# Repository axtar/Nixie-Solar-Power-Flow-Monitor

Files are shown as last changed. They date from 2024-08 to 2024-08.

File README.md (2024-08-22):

# Nixie Solar Power Flow Monitor
## This repository contains some information and ideas for building a nixie solar power flow monitor.


## WARNING: nixies need high voltage to light up. If you choose to build or use the device, you are doing so at your own risk. 

**Notes:**
- **The firmware is designed to work with a specific Fronius hybrid inverter using the Solar API V1. Firmware changes are needed for other inverters and configurations.**
- **This repository does not contain a complete project design. The design of the high voltage power supply (170V / ≥75mA) is not provided. I recommend using a professionally designed and extensively tested HV PSU.** 
- **Be aware that I'm just an electronics hobbyist and nixie enthusiast. However, this repository is only intended for suitable qualified electronics engineers who are familiar with nixie tubes.**
- **Please read all documents in [Docs](Docs) before deciding whether to build the device.**
- **I'm not affiliated with any of the service providers mentioned in this project.**
  
**Status:** 
- Software: ready to be reviewed (beta)
- Hardware: ready to be reviewed (beta)

**Displayed Values:**

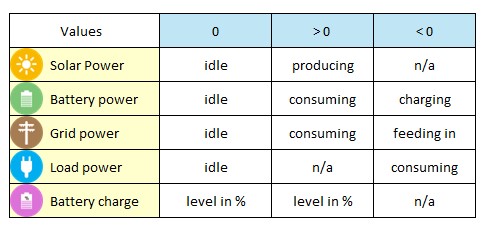
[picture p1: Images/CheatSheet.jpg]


**Nixie tubes used in this project:**
- 15 x IN-12A or IN-12B
- 10 x IN-15A
- 4 x IN-15B

**Additional Features:**

- LED backlight
- Ethernet connection

**Nixie Solar Power Flow Monitor**

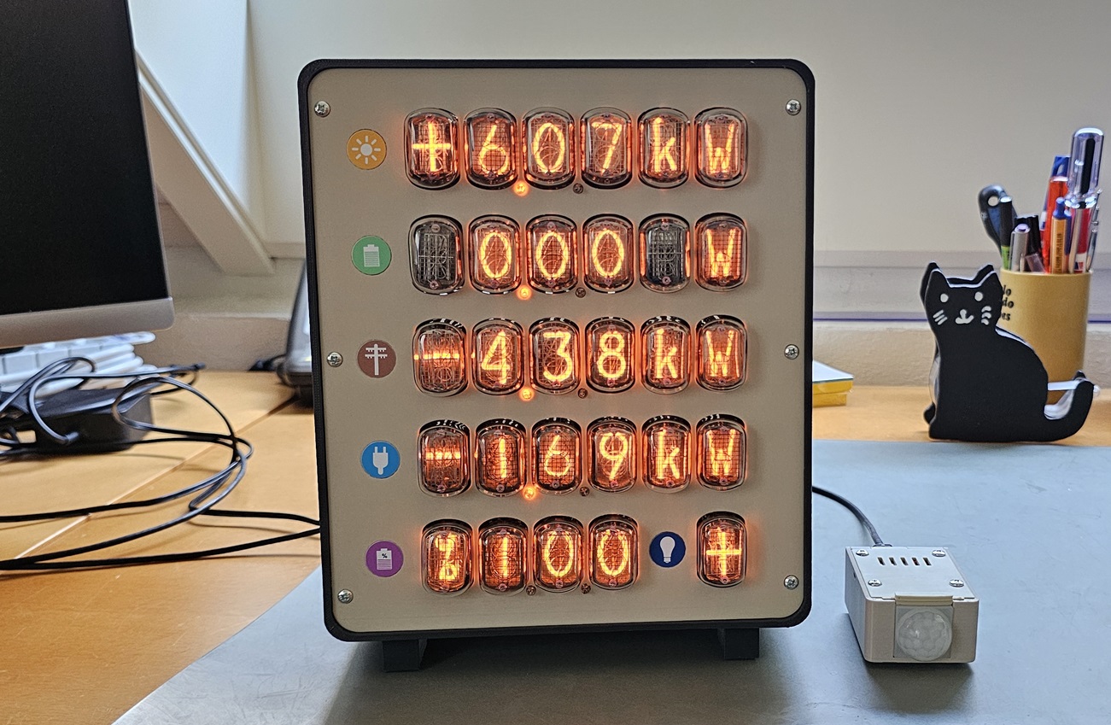
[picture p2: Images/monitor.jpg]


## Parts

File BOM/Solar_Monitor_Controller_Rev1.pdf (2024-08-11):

BOM Solar Monitor Controller Rev.1 | 10/08/2024
ID | Quantity | Value | Additional | Designator | Footprint | Type | Manufacturer Part | Manufacturer
1 | 1 | 1.2M | 1/4W, 1% | R1 | 0805 | Resistor | RK73H2ATTD1204F | KOA Speer
2 | 1 | 510k | 1/4W | R2 | 0805 | Resistor | RK73H2ATTD5103F | KOA Speer
3 | 1 | 15k | 1/4W, 1% | R3 | 0805 | Resistor | RK73H2ATTD1502F | KOA Speer
4 | 1 | 1k | 1/4W | R4 | 0805 | Resistor | RK73H2ATTDD1001F | KOA Speer
5 | 1 | 47k | 1/4W, 1% | R5 | 0805 | Resistor | RK73H2ATTD4702F | KOA Speer
6 | 2 | 10 | 1/4W | R6,R7 | 0805 | Resistor | RK73H2ATTD10R0F | KOA Speer
7 | 2 | 330 | 1/4W | R8,R12 | 0805 | Resistor | RK73H2ATTD3300F | KOA Speer
8 | 6 | 4.7k | 1/4W | R10,R11,R14,R17,R21,R23 | 0805 | Resistor | RK73H2ATTD4701F | KOA Speer
9 | 1 | 10k | 1/4W | R9 | 0805 | Resistor | RK73H2ATTD1002F | KOA Speer
10 | 4 | 150 | 1/4W | R13,R15,R16,R28 | 0805 | Resistor | RK73H2ATTD1500F | KOA Speer
11 | 1 | see schematic | 1/4W | R18 | 0805 | Resistor
12 | 1 | see schematic | 1/4W | R19 | 0805 | Resistor
13 | 4 | 3.9k | 1/4W | R20,R22,R26,R27 | 0805 | Resistor | RK73H2ATTD3901F | KOA Speer
14 | 1 | 220u | 25V | C1 | 8mm dia | Capacitor | GYB1E221MCQ1GS | Nichicon
15 | 9 | 100n | 50V | C2,C6,C10,C12-C17 | 0805 | Capacitor | C0805C104M5RACTU | KEMET
16 | 2 | 10u | 25V | C3,C7 | 1206 | Capacitor | TMK316BJ106MLHT | Taiyo Yuden
17 | 4 | 22u | 25V | C4,C5,C8,C9 | 1206 | Capacitor | TMK316BBJ226ML-T | Taiyo Yuden
18 | 1 | 10u | 16V | C11 | 0805 | Capacitor | GRM21BR61C106KE15K | Murata Electronics
19 | 1 | B340A-13-F | | D1 | SMA | Diode | B340A-13-F | Diodes Incorporated
20 | 1 | LED yellow | | LED1 | 1206 | LED | 599-0240-007F | Dialight
21 | 1 | LED red | | LED2 | 1206 | LED | 599-0210-007F | Dialight
22 | 1 | LED blue | | LED3 | 1206 | LED | 599-0291-007F | Dialight
23 | 1 | 3.9uH inductor | | L1 | 8043 | Inductor | SRU8043-3R9Y | Bourns
24 | 1 | 4.7uH inductor | | L2 | 8043 | Inductor | SRU8043-4R7Y | Bourns
25 | 1 | LTC4365 | | U1 | SOT-8 | IC | LTC4365ITS8-1#TRMPBF | Analog Devices
26 | 1 | AP63203WU-7 | | U2 | TSOT-26-6 | IC | AP63203WU-7 | Diodes Incorporated
27 | 1 | AP63205WU-7 | | U3 | TSOT-26-6 | IC | AP63205WU-7 | Diodes Incorporated
28 | 1 | ESP-WROOM-32E | 16MB | U4 | | MC module | ESP32-WROOM-32E-N16 | Espressif Systems
29 | 1 | CD40109B | | U5 | SO-16 | IC | CD40109BNSR | Texas Insruments
30 | 1 | DS3231MZ+ | | U6 | SOIC-8 | IC | DS3231MZ+TRL | Maxim Integrated
31 | 1 | CSD88537ND Dual N | | Q1 | SOIC-8 | Mosfet | CSD88537ND | Texas Insruments
32 | 3 | BSS138 | | Q2,Q3,Q4 | SOT-23 | Mosfet | BSS138N H6327 | Infineon Technologies
33 | 1 | DC power connector | | DCIN | | DC power connector | PJ-057AH | CUI Devices
34 | 1 | Fuse 1.6A Fast | | F1 | | Fuse | 0034.6016 | Schurter
35 | 1 | Fuse holder | | | | Fuse holder | 0031.7601 | Schurter
36 | 2 | Tactile Switch | | SW1,SW2 | | Switch | TL1105AF160Q | E-Switch
37 | 1 | Tactile Switch | right angle | BUTTON1 | | Switch | TL1105SF160Q | E-Switch
38 | 1 | CR2032 battery holder | | | | Battery holder | SMTU2032-LF | Renata
39 | 1 | CR2032 battery | | B1 | | Battery
40 | 2 | 1x2 header/2.54mm | male | SWITCH, IOEX | | Header
41 | 1 | 1x3 header/2.54mm | male | LED | | Locking header
42 | 1 | 1x3 header/2.54mm | male | J1 | | Header
43 | *1 | 1x6 header/2.54mm | male, right angle | ETHERNET | | Locking header
44 | 2 | 1x4 header/2.54mm | male | I2C | | Locking header
45 | 1 | 1x6 header/2.54mm | male | FLASH | | Header
46 | 1 | 1x6 header/2.54mm | male | DRIVER | | Locking header
47 | 1 | 3 poles terminal block | | TOHVPSU | | Fixed Terminal Block | TB006-508-03BE | CUI Devices
48 | 1 | RJ45 Jack | female | PERIPHERALS | see datasheet | RJ45 jack | 615008142621 | Würth Elektronik
* install on the bottom side off the board (different as drawn on the silkscreen)

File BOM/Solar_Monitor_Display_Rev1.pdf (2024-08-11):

BOM Solar Monitor Display Rev.1 | 10/08/2024
ID | Quantity | Value | Additional | Designator | Footprint | Type | Manufacturer Part | Manufacturer | Supplier Part | Supplier
1 | 6 | 18k | 1/4W | R1-R6 | 0805 | Resistor | RK73H2ATTD1802F | KOA Speer | 660-RK73H2ATTD1802F | Mouser
2 | 2 | 270k | 1/4W | R7-R8 | 0805 | Resistor | RK73H2ATTD2703F | KOA Speer | 660-RK73H2ATTD2703F | Mouser
3 | 2 | IN-15A Nixie | | N1,N5 | | Nixie tube
4 | 3 | IN-12 Nixie | | N2-N4 | | Nixie tube
5 | 1 | IN-15B Nixie | | N6 | | Nixie tube
6 | 2 | Neon 4mm | | E1-E2 | | Neon lamp
7 | 1 | 2 poles terminal block | | HV | | Fixed Terminal Block | TB006-508-02BE | CUI Devices | 490-TB006-508-02BE | Mouser
8 | 12 | 1x6 Header | female, 200V | H1-H12 | | Header
9 | 72 | Single receptacle contacts | for 1mm pins
on the board for the battery charge value, do not populate N5 and populate N6 with an IN-15A nixie tube

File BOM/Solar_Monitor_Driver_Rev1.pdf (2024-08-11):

BOM Solar Monitor Driver Rev.1 | 10/08/2024
ID | Quantity | Value | Additional | Designator | Footprint | Type | Manufacturer Part | Manufacturer
1 | 2 | 100n | 50V | C1-C2 | 0805 | Capacitor | C0805C104M5RACTU | KEMET
2 | 2 | HV5622 | | U1-U2 | PQFP-44 | IC | HV5622PG-G | Microchip Technology
3 | 12 | 1x6 header 2.54mm | male, 200V | J1-J12 | | Header
4 | 2 | 1x6 header, 2.54mm | male | H1,H2 | | Locking header
5 | 2 | 1x3 header, 2.54mm | male | J13,J15 | | Header
6 | 2 | 1x3 header, 2.54mm | male | J14,J16 | | Locking header

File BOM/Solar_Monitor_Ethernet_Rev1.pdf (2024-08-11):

BOM Solar Monitor Ethernet Rev.1 | 10/08/2024
ID | Quantity | Value | Additional | Designator | Footprint | Type | Manufacturer Part | Manufacturer
1 | *1 | W5500-Lite | | U1 | | Ethermet module | WIZ850IO or SBC-USR-ES1 | WIZnet/joy-it
2 | **1 | 1x6 header/2.54mm | male | J3 | | Locking header
* only testet with the joy-it module
** mount on the bottom side of the board (different as drawn on the silkscreen)
do not populate J1 and J2

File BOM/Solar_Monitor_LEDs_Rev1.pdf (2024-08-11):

BOM Solar Monitor LEDs Rev.1 | 10/08/2024
ID | Quantity | Value | Additional | Designator | Footprint | Type | Manufacturer Part | Manufacturer
1 | *1 | 150 | 1/4W | R1 | 0805 | Resistor | RK73H2ATTD1500F | KOA Speer
2 | *1 | 0 | | R1 | 0805 | Resistor | RK73Z2ATTD | KOA Speer
3 | 1 | 47uF | 25V | C1 | 1206 | Capacitor | C3216X5R1E476M160AC | TDK
4 | 6 | Neopixel RGB SK6812 | | D1-D6 | 5050 | RGB LED | SK6812
* populate with 150 ohms on the board directly connected to the controller and with a 0 ohms jumper on the other boards
do not populate H1 and H2

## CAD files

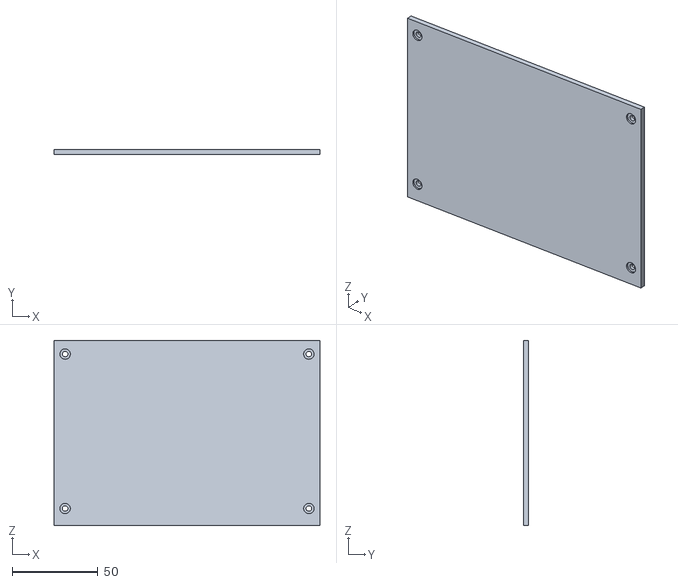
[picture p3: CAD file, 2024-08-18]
3D_Prints/Case/STL/Solar Monitor Side.stl
155.0 x 3.00 x 108.0

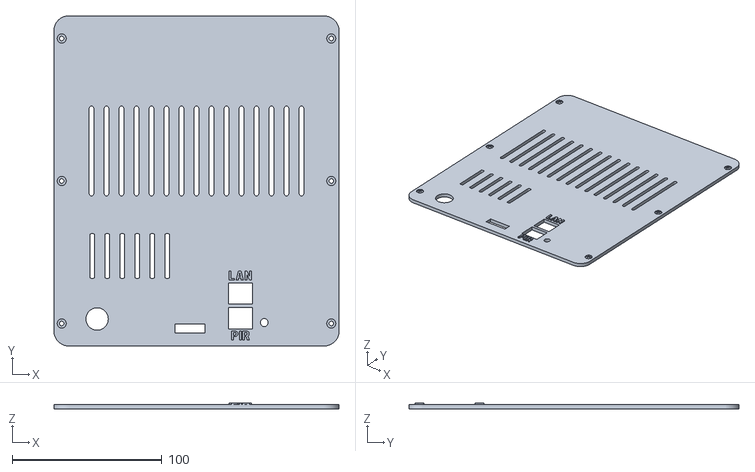
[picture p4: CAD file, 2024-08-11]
3D_Prints/Case/STL/Solar Monitor Rear.stl
190.0 x 220.0 x 4.00

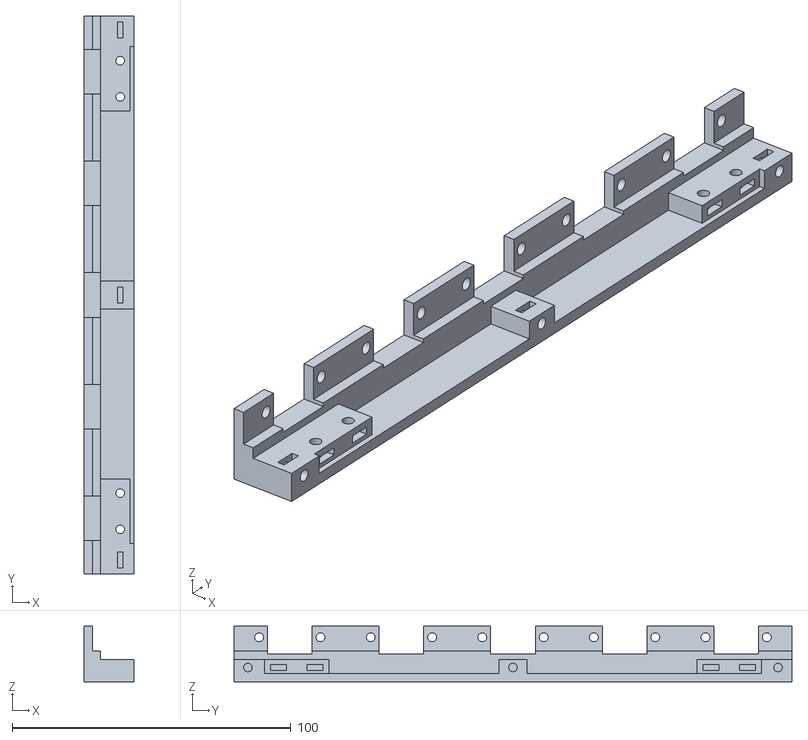
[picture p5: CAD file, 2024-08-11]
3D_Prints/Case/STL/Solar Monitor Support Front Right.stl
18.0 x 200.0 x 20.0

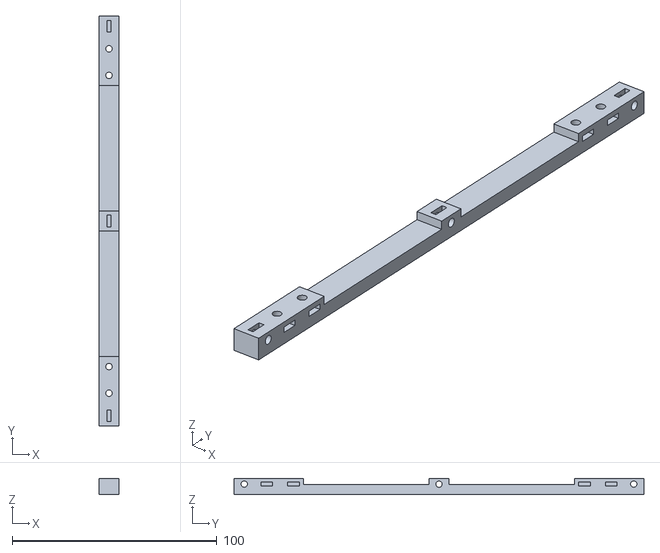
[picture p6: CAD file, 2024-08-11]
3D_Prints/Case/STL/Solar Monitor Support Rear.stl
10.0 x 200.0 x 8.00

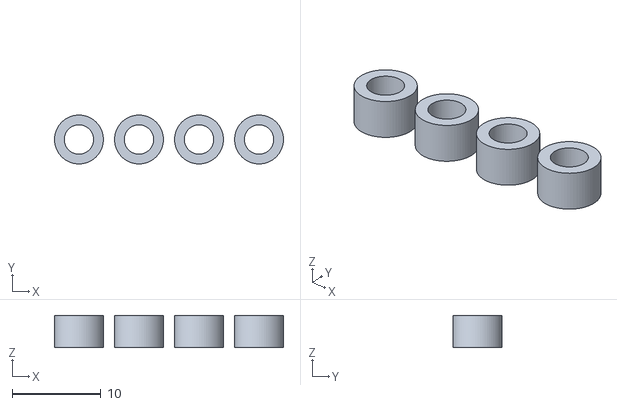
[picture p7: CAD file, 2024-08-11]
3D_Prints/Case/STL/Solar Monitor W5500 Standoffs.stl
25.8 x 5.50 x 3.60

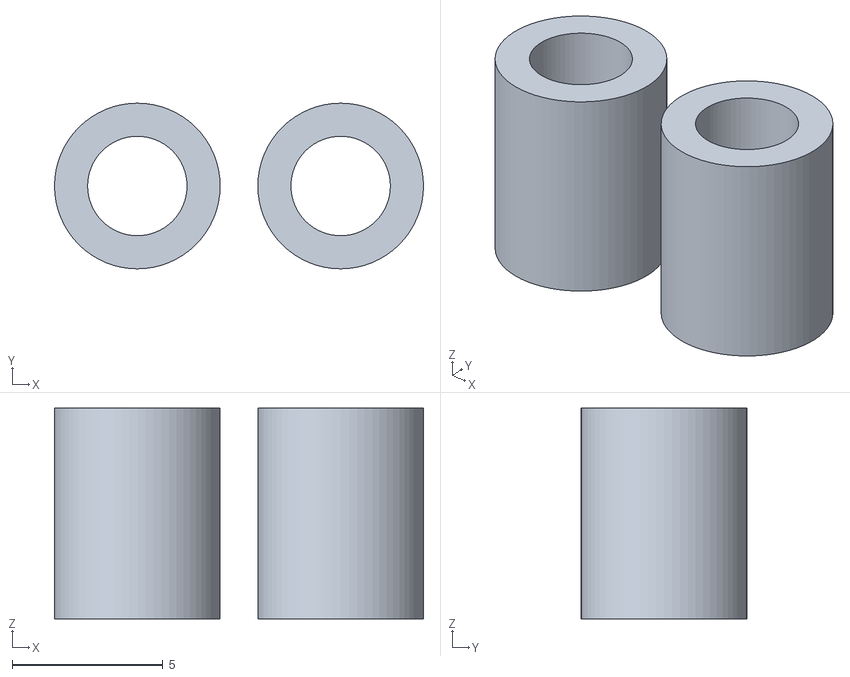
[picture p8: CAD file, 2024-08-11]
3D_Prints/Case/STL/Solar Monitor LED Board Standoff Template.stl
12.2 x 5.50 x 7.00

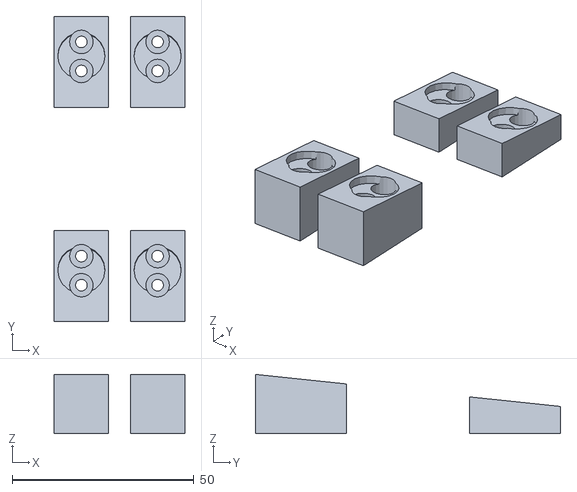
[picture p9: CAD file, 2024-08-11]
3D_Prints/Case/STL/Solar Monitor Feet 6 Degrees.stl
36.0 x 84.0 x 16.3

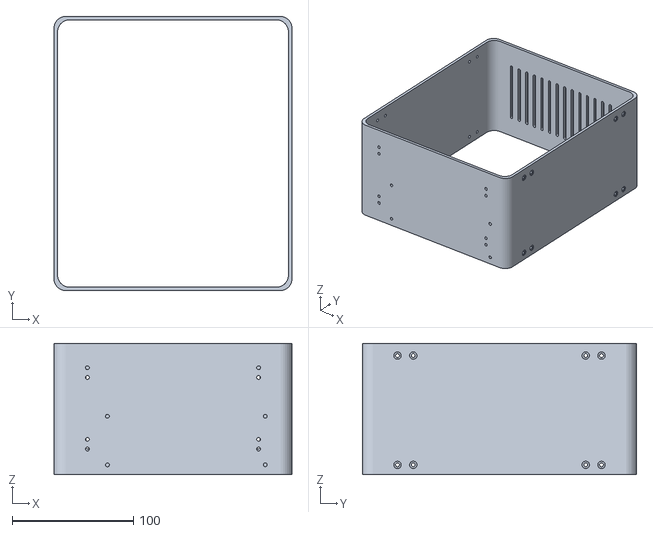
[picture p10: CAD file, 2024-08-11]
3D_Prints/Case/STL/Solar Monitor Base.stl
196.0 x 226.0 x 108.0

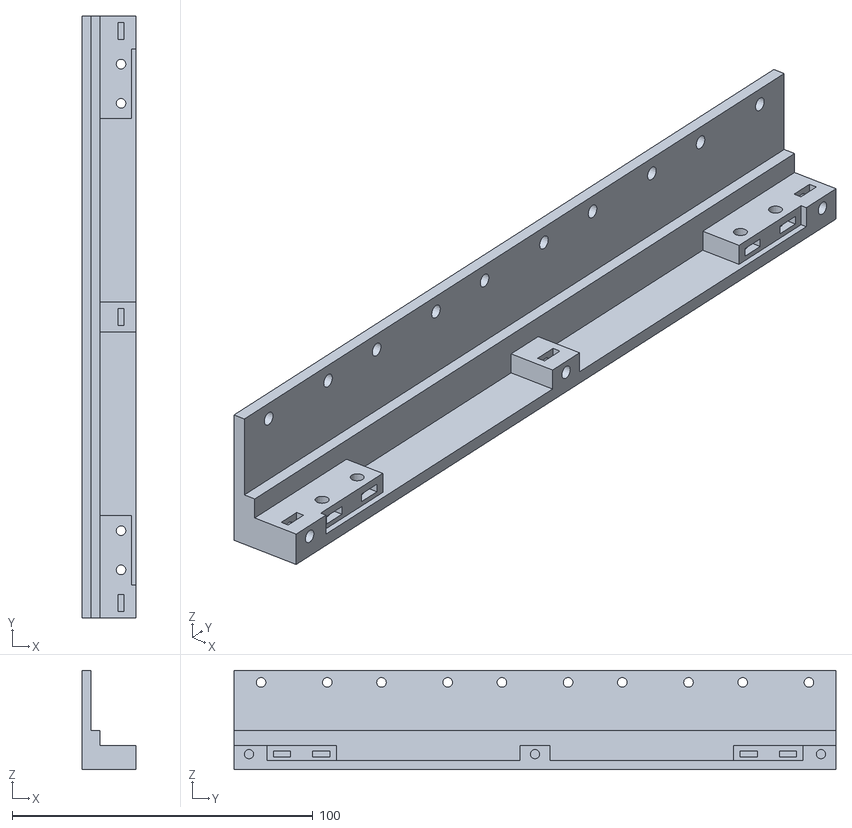
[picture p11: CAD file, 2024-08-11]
3D_Prints/Case/STL/Solar Monitor Support Front Left.stl
18.0 x 200.0 x 33.0

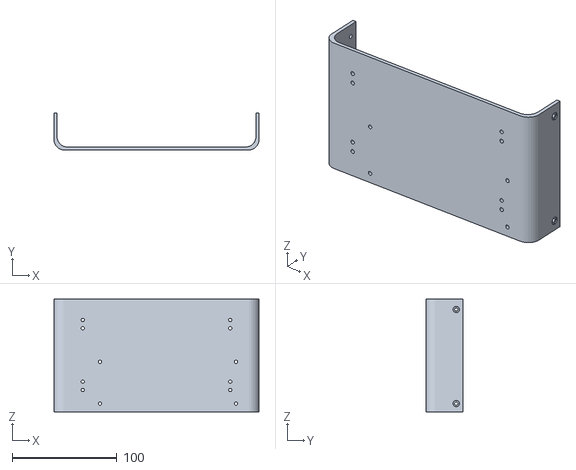
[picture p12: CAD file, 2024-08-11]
3D_Prints/Case/STL/Solar Monitor Bottom.stl
196.0 x 35.5 x 108.0

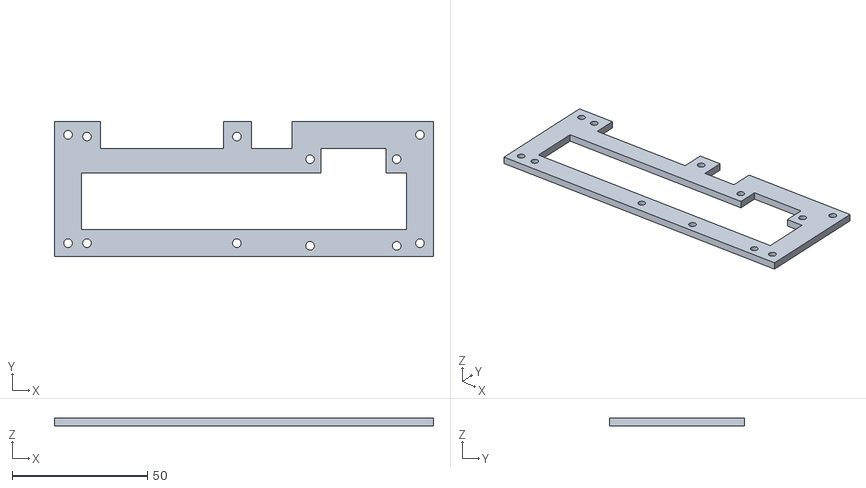
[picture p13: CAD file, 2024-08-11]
3D_Prints/Case/STL/Solar Monitor PSU Mount.stl
140.0 x 50.0 x 3.00

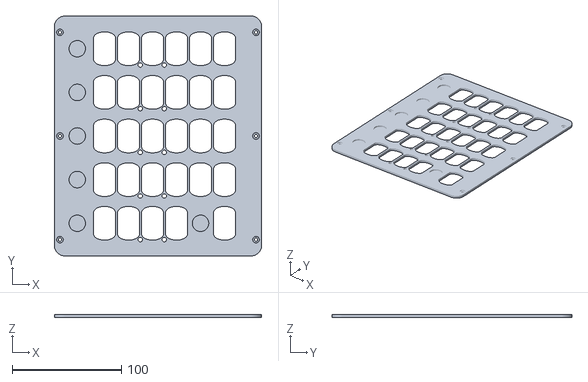
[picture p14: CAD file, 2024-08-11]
3D_Prints/Case/STL/Solar Monitor Front.stl
190.0 x 220.0 x 3.00

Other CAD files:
3D_Prints/Case/STL/Solar Monitor Top.stl

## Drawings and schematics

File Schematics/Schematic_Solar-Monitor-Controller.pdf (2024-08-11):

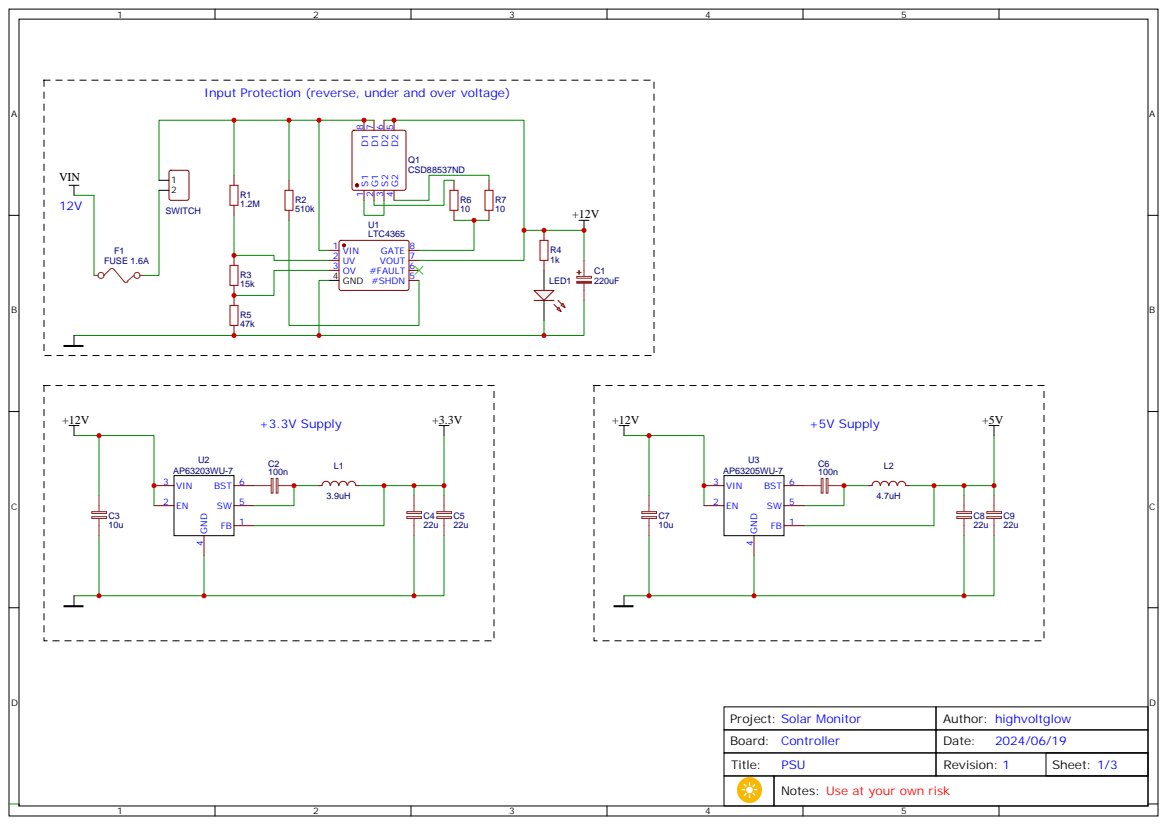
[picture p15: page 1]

Input Protection (reverse, under and over voltage)

Notes: Use at your own risk

IO0 25 IO4 26 IO16 27 IO17 28 IO5 29 IO18 30 IO19 31 NC 32 IO21 33 RXD0 34 TXD0 35 IO22 36 IO23 37 GND 38

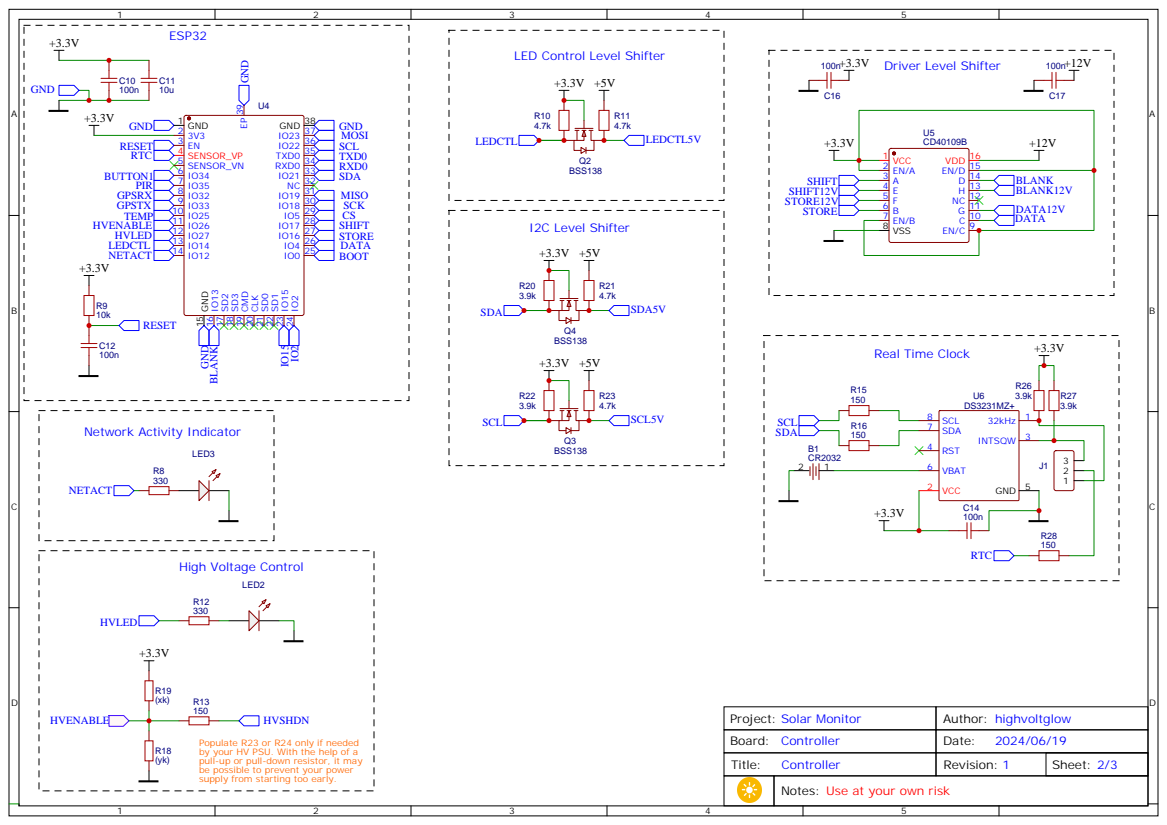
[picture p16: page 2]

LED Control Level Shifter

Populate R23 or R24 only if needed
by your HV PSU. With the help of a
pull-up or pull-down resistor, it may
be possible to prevent your power
supply from starting too early.

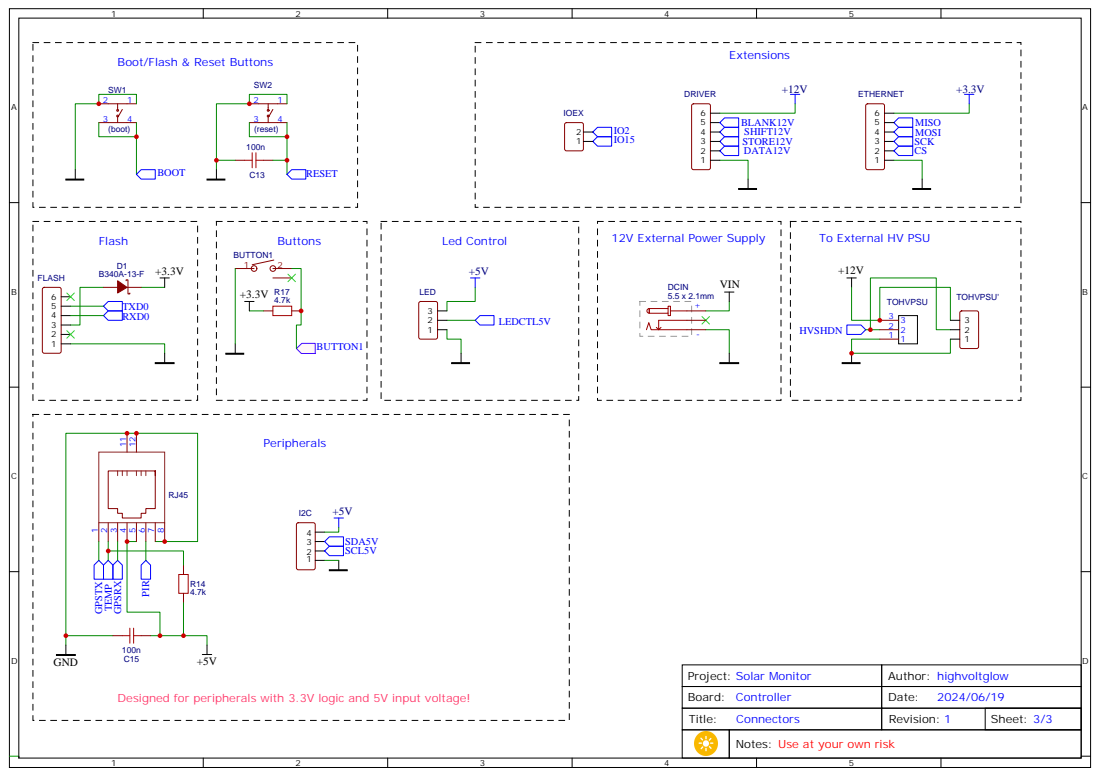
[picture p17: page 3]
HVSHDN; BUTTON1; DCIN; RXD0; TXD0; LEDCTL5V; Peripherals; Extensions; Buttons; Flash; Led Control; To External HV PSU; VIN; LED; TOHVPSU; BOOT; RESET; (boot); (reset); DATA12V; SHIFT12V STORE12V; TOHVPSU'; FLASH; DRIVER; BLANK12V; GPSTX; GPSRX; PIR; TEMP; GND; Title:; Connectors; Revision:; Date:; Author: highvoltglow; MISO; ETHERNET; SCK; MOSI; IOEX; SDA5V SCL5V

Boot/Flash & Reset Buttons

12V External Power Supply

Project: Solar Monitor
Board: Controller

Designed for peripherals with 3.3V logic and 5V input voltage!

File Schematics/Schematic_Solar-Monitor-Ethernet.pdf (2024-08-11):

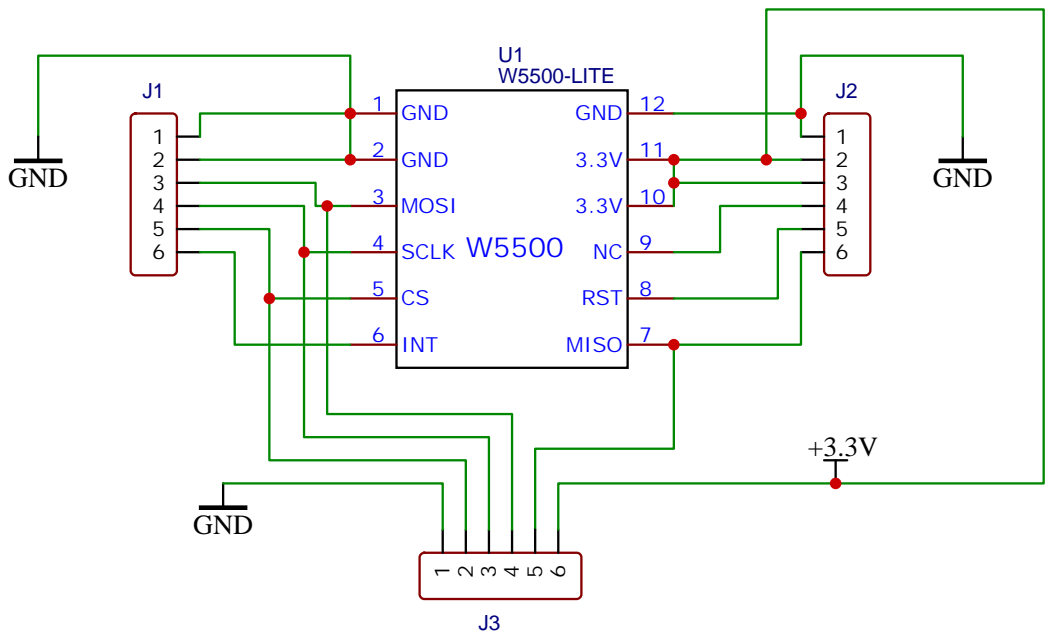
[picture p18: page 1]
Title:; Ethernet; Revision:; Date:; Author: highvoltglow; Sheet:; W5500-LITE; GND 1; GND 2; MOSI 3; SCLK 4; INT 6; GND 12; RST 8; MISO 7; GND

Project: Solar Monitor
Board: Ethernet

Notes: Use at your own risk

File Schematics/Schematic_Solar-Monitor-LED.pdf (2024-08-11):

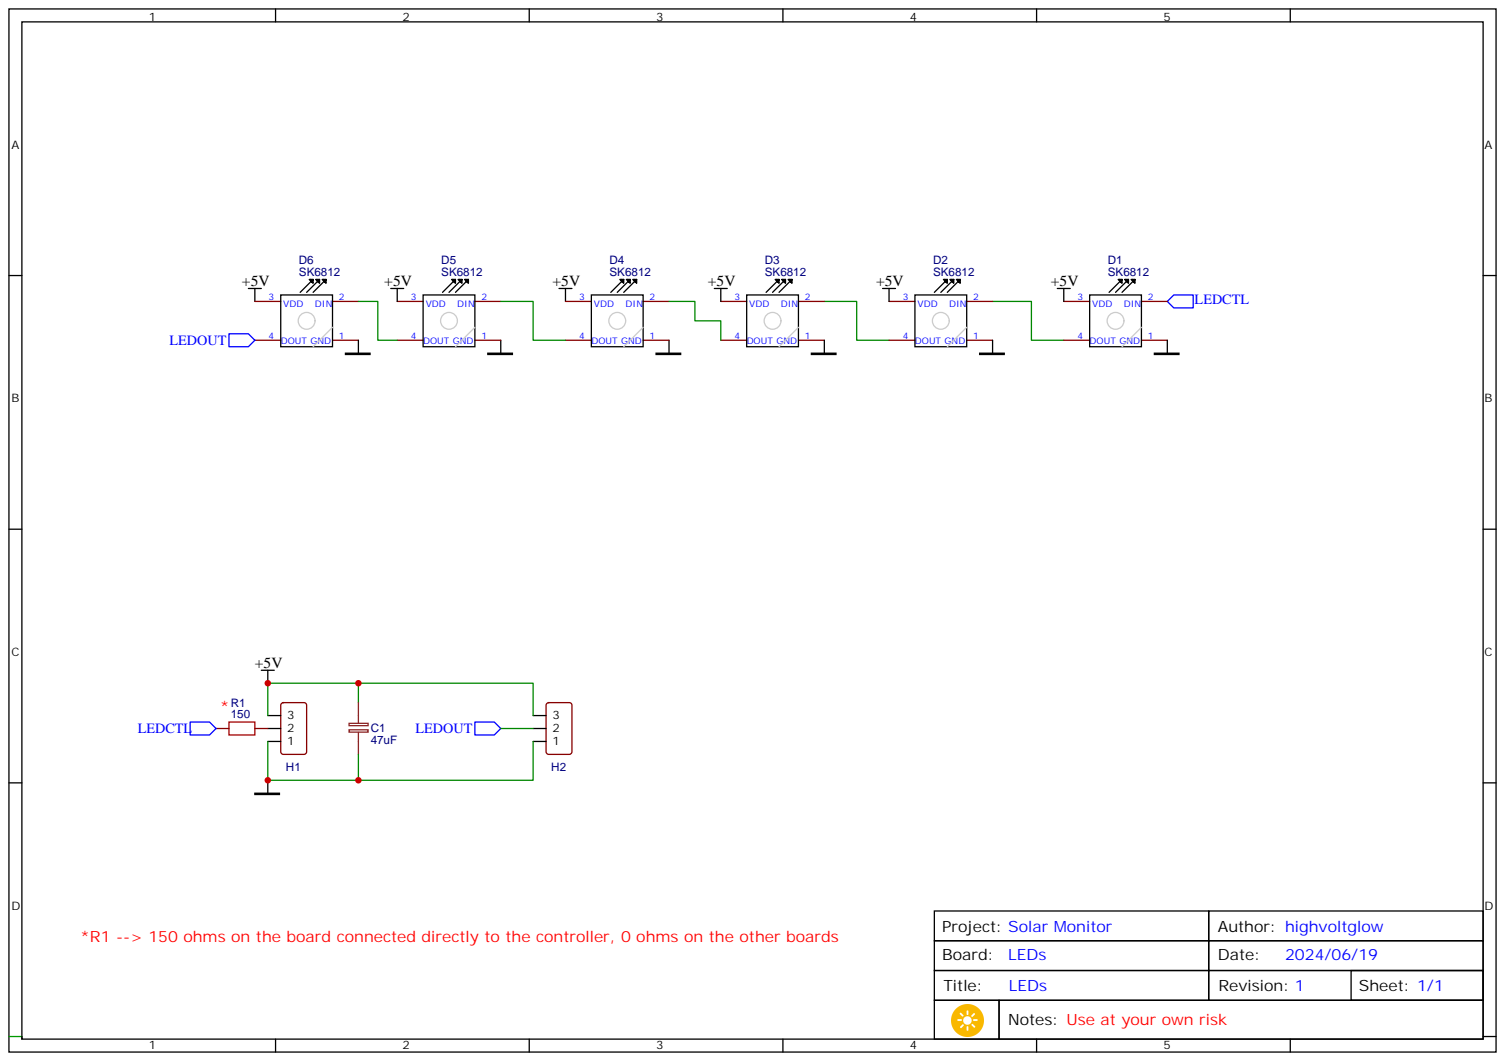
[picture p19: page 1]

*R1 --> 150 ohms on the board connected directly to the controller, 0 ohms on the other boards

Notes: Use at your own risk

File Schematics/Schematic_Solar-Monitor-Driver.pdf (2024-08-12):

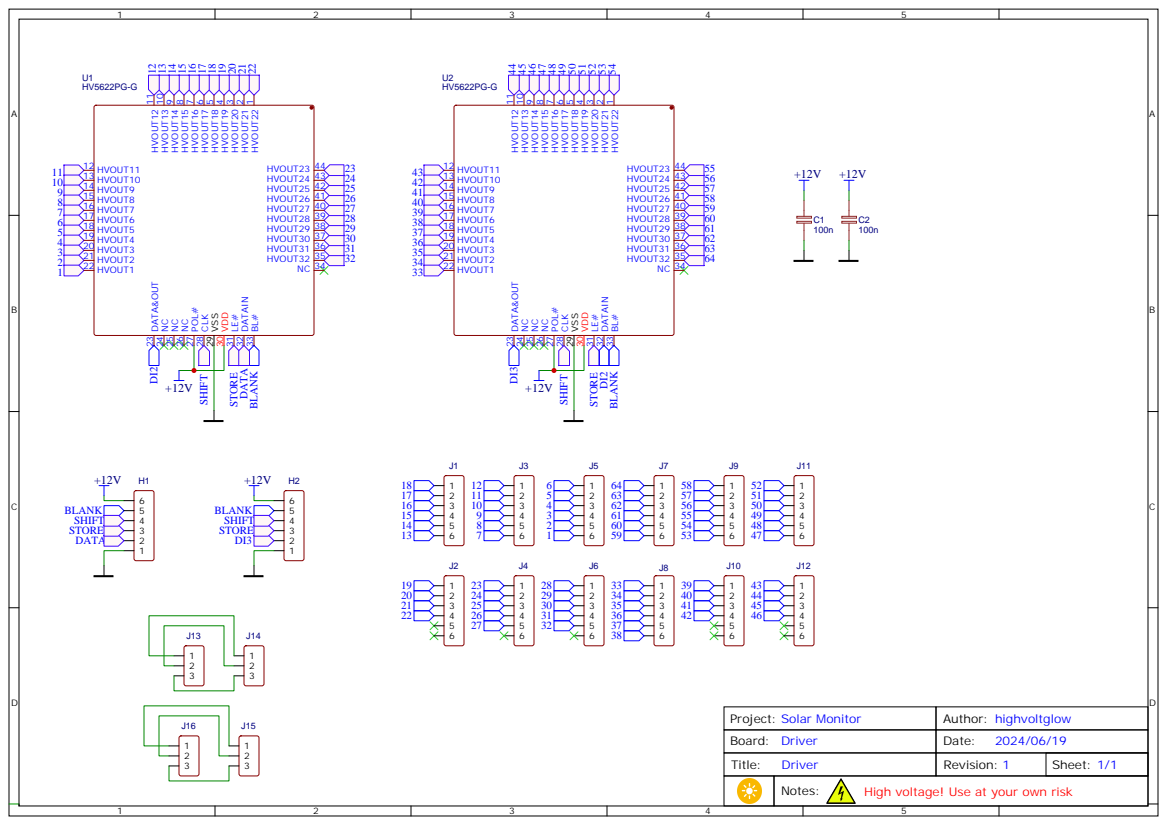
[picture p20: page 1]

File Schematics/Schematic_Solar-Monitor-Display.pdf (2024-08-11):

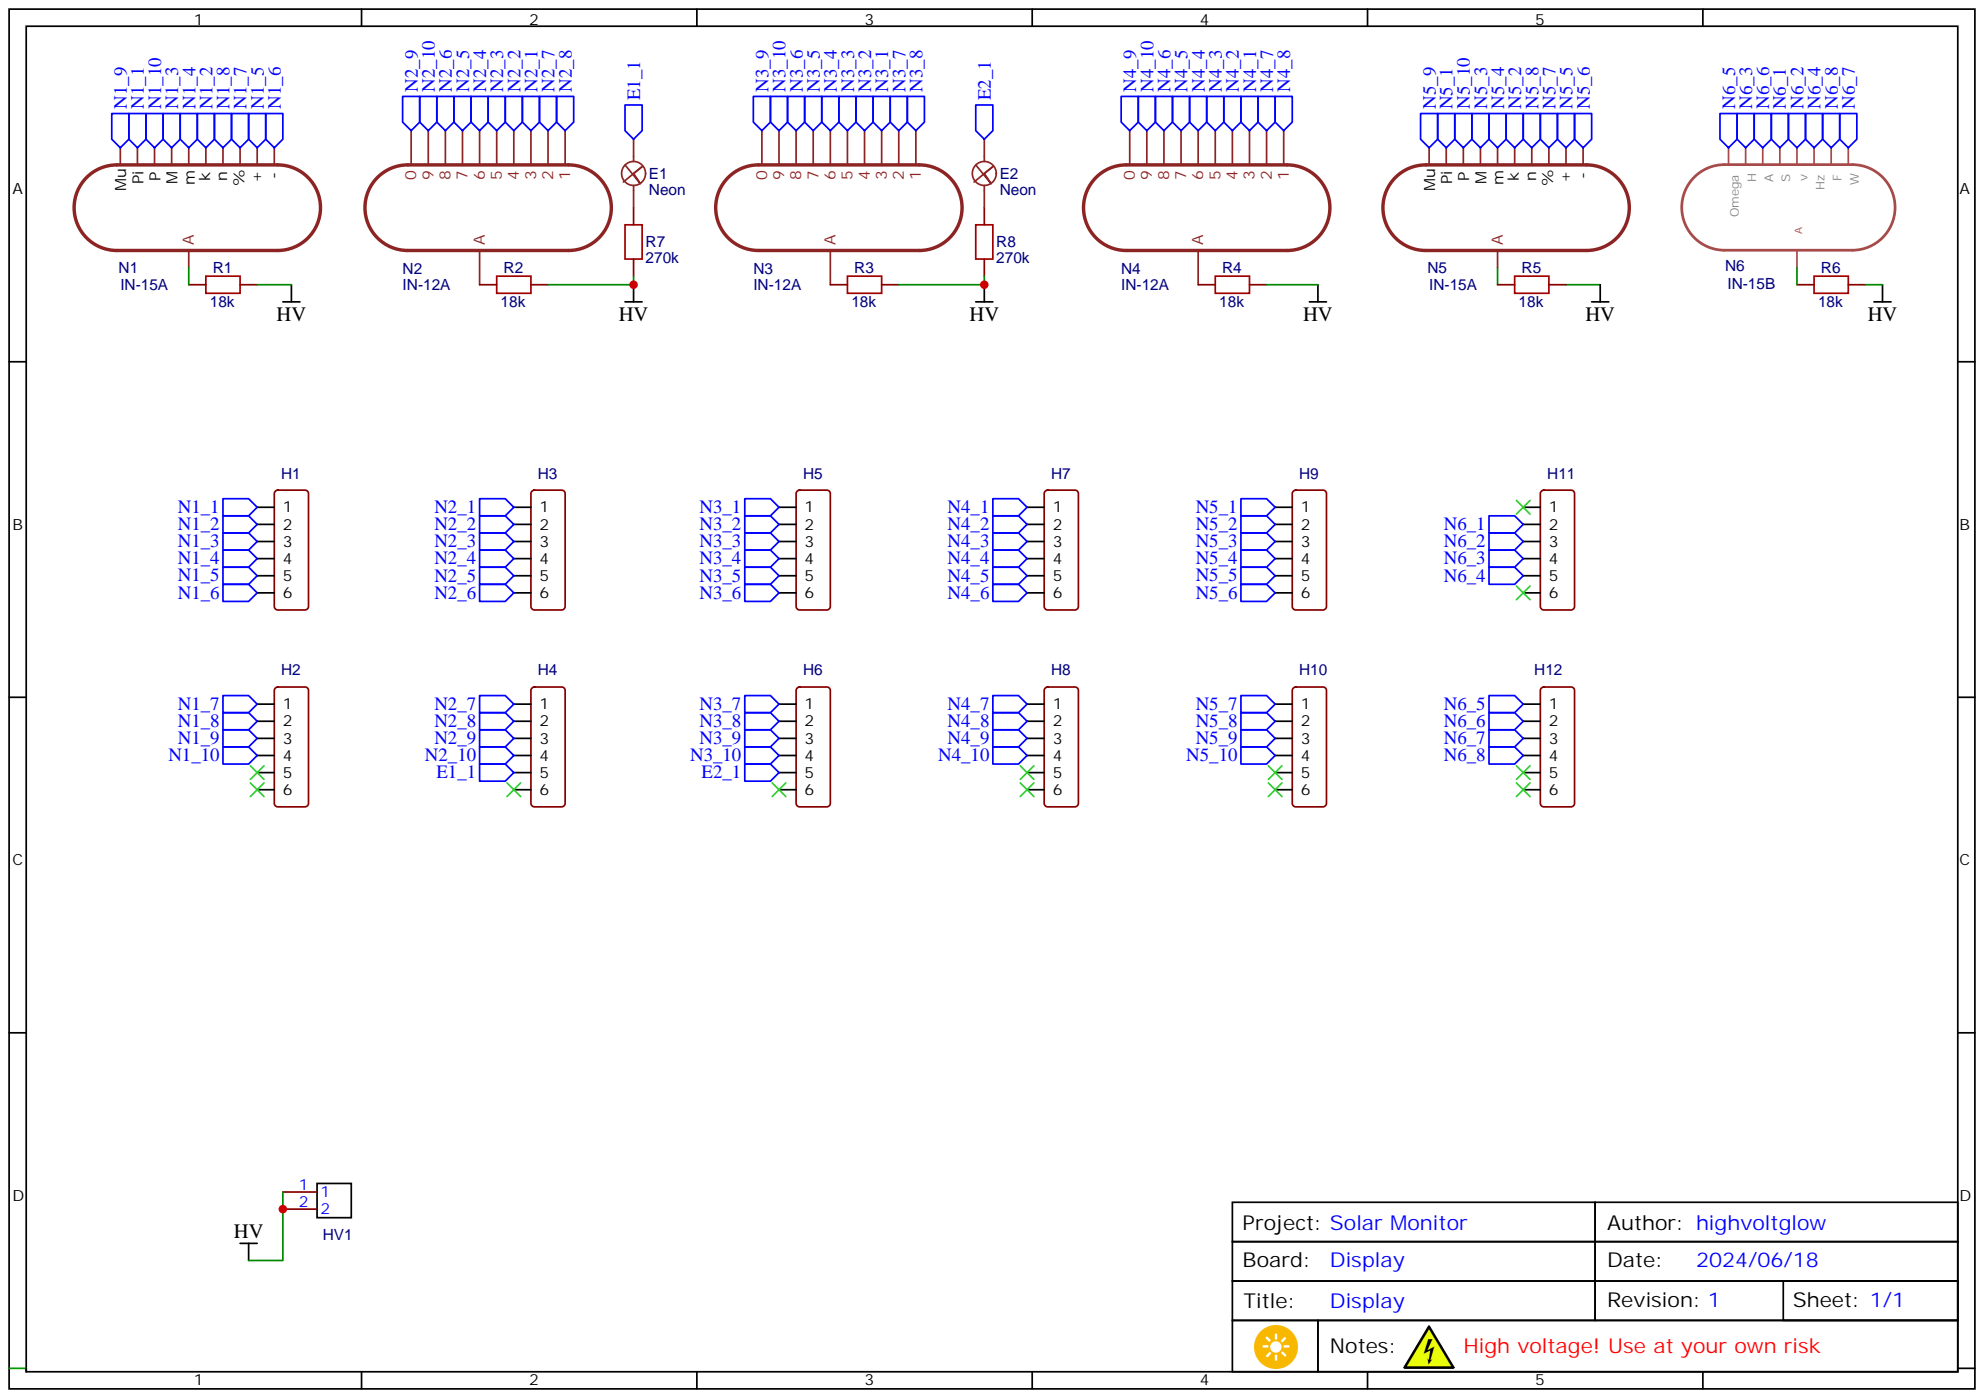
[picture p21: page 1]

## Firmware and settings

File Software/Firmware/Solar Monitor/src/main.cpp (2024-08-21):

// main.cpp

// Solar Monitor Firmware

// Copyright (C) 2024 highvoltglow
// Licensed under the MIT License

#include <main.h>

void setup()
{
  // init console
  D_Begin(115200);

  D_print("Initializing controller...");
  int status = controller.begin();
  if (status != ERR_SUCCESS)
  {
    D_print("Controller initialization failed. Error: ");
    D_print(status);
    D_print(" ");
    D_println(Errors::getErrorText(status));
    // error in initialization, stop
    while (true)
      ;
  }
  else
  {
    D_println("Controller successfully initialized");
  }
}

void loop()
{
  if (!controller.process())
  {
    // error in controller process, stop
    D_print("Error in controller process, stopping...");
    while (true)
      ;
  }
}

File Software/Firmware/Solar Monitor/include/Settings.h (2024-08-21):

// Settings.h

// adjustable settings

// Copyright (C) 2024 highvoltglow
// Licensed under the MIT License

#pragma once

// HV shutdown delay
#define PIR_DELAY 5 // in minutes, 0 disables PIR

// cathode poisoning
#define ROTATION_INTERVAL 5       // in minutes
#define ROTATION_STEPINTERVAL 250 // in ms

// the solar API V1 allows a polling interval down to 4 seconds, don't go below this
#define INVERTER_POLLINGINTERVAL 5 // in seconds

// IP address of the inverter
#define INVERTER_IPADDRESS "x.x.x.x"

// Inverter connection port
#define INVERTER_PORT 80

// values in the defined range are set to 0 to keep the display quieter
// set this value to 0 if you dont want to round towards zero
#define POWER_ROUND_TO_ZERO_RANGE 10 // in watts

// methods to get the load power value
#define LOADPOWER_CALCULATE 1    // calculate the load power using the grid, solar and battery power values
#define LOADPOWER_FROMINVERTER 2 // take the load power value provided by the inverter, always slightly lower as calculated

// used method to get the load power value
#define GET_LOADPOWER_METHOD LOADPOWER_CALCULATE

// rating backlight colors R, G, B
#define COLOR_EXCELLENT 0, 153, 153
#define COLOR_GOOD 0, 255, 0
#define COLOR_FAIR 255, 100, 0
#define COLOR_POOR 255, 0, 0

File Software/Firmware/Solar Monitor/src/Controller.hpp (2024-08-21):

// Controller.hpp

// main logic

// Copyright (C) 2024 highvoltglow
// Licensed under the MIT License

#pragma once

#include <esp_mac.h>
#include <Arduino.h>
#include <SPI.h>
#include <Ethernet.h>
#include <Adafruit_NeoPixel.h>
#include <Button.hpp>
#include <DebugDefs.h>
#include <Helper.hpp>
#include <Display.hpp>
#include <PIR.hpp>
#include <Inverter.hpp>
#include <Errors.hpp>
#include <Settings.h>

// IO pins
#define PIN_BUTTON1 34
#define PIN_PIR 35
#define PIN_GPSRX 32
#define PIN_GPSTX 33
#define PIN_TEMP 25
#define PIN_HVENABLE 26
#define PIN_HVLED 27
#define PIN_LEDCTL 14
#define PIN_NETACT 12
#define PIN_BLANK 13
#define PIN_DATA 4
#define PIN_STORE 16
#define PIN_SHIFT 17
#define PIN_CS 5
#define PIN_SCK 18
#define PIN_MISO 19
#define PIN_SDA 21
#define PIN_SCL 22
#define PIN_MOSI 23

// shift register store transition
#define STORE_BEGIN LOW
#define STORE_COMMIT HIGH

// number of display boards
#define DISPLAY_COUNT 5

// display number with the overall status
#define OVERALL_DISPLAY_NUMBER 4

enum class backlight_mode
{
  off,
  overall_only,
  full
};

class Controller
{
public:
  Controller() : _button(PIN_BUTTON1)
  {
    _highVoltageOn = true;
    _lastRequestTimestamp = 0;
    _backLight = backlight_mode::off;
    _backLightState = true;
    _lastRotationTimestamp = millis();
    _lastRotationStepTimestamp = 0;
    _rotationStep = 0;
    _rotation = false;

    // initialize displays
    // solar power display
    _displays[0] = new Display(display_type::solar_power, value_type ::watts,
                               PIN_DATA, PIN_STORE, PIN_SHIFT,
                               PIN_BLANK, PIN_LEDCTL);
    _displays[0]->getBacklight()->setRating(rating_step::poor, 0, 250, Helper::rgbToInt(COLOR_POOR));
    _displays[0]->getBacklight()->setRating(rating_step::fair, 251, 1500, Helper::rgbToInt(COLOR_FAIR));
    _displays[0]->getBacklight()->setRating(rating_step::good, 1501, 5000, Helper::rgbToInt(COLOR_GOOD));
    _displays[0]->getBacklight()->setRating(rating_step::excellent, 5001, 999999, Helper::rgbToInt(COLOR_EXCELLENT));
    _displays[0]->getBacklight()->setMinLED(24);
    _displays[0]->getBacklight()->setMaxLED(29);

    // battery power display
    _displays[1] = new Display(display_type::battery_power, value_type ::watts,
                               PIN_DATA, PIN_STORE, PIN_SHIFT,
                               PIN_BLANK, PIN_LEDCTL);
    _displays[1]->getBacklight()->setRating(rating_step::poor, 1501, 999999, Helper::rgbToInt(COLOR_POOR));
    _displays[1]->getBacklight()->setRating(rating_step::fair, 0, 1500, Helper::rgbToInt(COLOR_FAIR));
    _displays[1]->getBacklight()->setRating(rating_step::good, -3001, 1, Helper::rgbToInt(COLOR_GOOD));
    _displays[1]->getBacklight()->setRating(rating_step::excellent, -999999, -3000, Helper::rgbToInt(COLOR_EXCELLENT));
    _displays[1]->getBacklight()->setMinLED(18);
    _displays[1]->getBacklight()->setMaxLED(23);

    // grid power display
    _displays[2] = new Display(display_type::grid_power, value_type ::watts,
                               PIN_DATA, PIN_STORE, PIN_SHIFT,
                               PIN_BLANK, PIN_LEDCTL);
    _displays[2]->getBacklight()->setRating(rating_step::poor, 1501, 999999, Helper::rgbToInt(COLOR_POOR));
    _displays[2]->getBacklight()->setRating(rating_step::fair, 0, 1500, Helper::rgbToInt(COLOR_FAIR));
    _displays[2]->getBacklight()->setRating(rating_step::good, -3001, 1, Helper::rgbToInt(COLOR_GOOD));
    _displays[2]->getBacklight()->setRating(rating_step::excellent, -999999, -3000, Helper::rgbToInt(COLOR_EXCELLENT));
    _displays[2]->getBacklight()->setMinLED(12);
    _displays[2]->getBacklight()->setMaxLED(17);

    // load power display
    _displays[3] = new Display(display_type::load_power, value_type ::watts,
                               PIN_DATA, PIN_STORE, PIN_SHIFT,
                               PIN_BLANK, PIN_LEDCTL);
    _displays[3]->getBacklight()->setRating(rating_step::poor, -999999, -1501, Helper::rgbToInt(COLOR_POOR));
    _displays[3]->getBacklight()->setRating(rating_step::fair, -1500, -501, Helper::rgbToInt(COLOR_FAIR));
    _displays[3]->getBacklight()->setRating(rating_step::good, -500, -251, Helper::rgbToInt(COLOR_GOOD));
    _displays[3]->getBacklight()->setRating(rating_step::excellent, -250, 0, Helper::rgbToInt(COLOR_EXCELLENT));
    _displays[3]->getBacklight()->setMinLED(6);
    _displays[3]->getBacklight()->setMaxLED(11);

    // battery charge display
    _displays[4] = new Display(display_type::battery_charge, value_type ::battery_charge,
                               PIN_DATA, PIN_STORE, PIN_SHIFT,
                               PIN_BLANK, PIN_LEDCTL);
    _displays[4]->getBacklight()->setRating(rating_step::poor, 0, 10, Helper::rgbToInt(COLOR_POOR));
    _displays[4]->getBacklight()->setRating(rating_step::fair, 11, 50, Helper::rgbToInt(COLOR_FAIR));
    _displays[4]->getBacklight()->setRating(rating_step::good, 51, 90, Helper::rgbToInt(COLOR_GOOD));
    _displays[4]->getBacklight()->setRating(rating_step::excellent, 91, 100, Helper::rgbToInt(COLOR_EXCELLENT));
    _displays[4]->getBacklight()->setMinLED(0);
    _displays[4]->getBacklight()->setMaxLED(3);

    // this display has also the overall status indicator with separate settings for the rating
    _displays[4]->getOverallBacklight()->setRatingColor(overall_rating::poor, Helper::rgbToInt(COLOR_POOR));
    _displays[4]->getOverallBacklight()->setRatingColor(overall_rating::fair, Helper::rgbToInt(COLOR_FAIR));
    _displays[4]->getOverallBacklight()->setRatingColor(overall_rating::good, Helper::rgbToInt(COLOR_GOOD));
    _displays[4]->getOverallBacklight()->setRatingColor(overall_rating::excellent, Helper::rgbToInt(COLOR_EXCELLENT));
    _displays[4]->getOverallBacklight()->setMinLED(5);
    _displays[4]->getOverallBacklight()->setMaxLED(5);

    _ledCount = 0;
    for (int i = 0; i < DISPLAY_COUNT; i++)
    {
      _ledCount += _displays[i]->getLedCount();
    }
    _leds = new Adafruit_NeoPixel(_ledCount, PIN_LEDCTL, NEO_GRB + NEO_KHZ800);
    _leds->begin();

    _pir = new PIR(PIN_PIR, PIR_DELAY);
  }

  virtual ~Controller()
  {
    delete (_pir);
    for (int i = 0; i < DISPLAY_COUNT; i++)
    {
      delete (_displays[i]);
      delete (_leds);
    }
  }

  // initialization
  int begin()
  {
    int result = ERR_SUCCESS;

    // clear leds
    clearLEDs();

    // set high voltage off
    pinMode(PIN_HVENABLE, OUTPUT);
    pinMode(PIN_HVLED, OUTPUT);
    hvOFF();

    // define pin modes
    pinMode(PIN_PIR, INPUT);
    pinMode(PIN_DATA, OUTPUT);
    pinMode(PIN_STORE, OUTPUT);
    pinMode(PIN_SHIFT, OUTPUT);
    pinMode(PIN_BLANK, OUTPUT);
    pinMode(PIN_BUTTON1, INPUT);

    // set blank line to high
    digitalWrite(PIN_BLANK, HIGH);

    clearDisplays();

    // initialize PIR
    _pir->begin();

    // high voltage on
    hvON();
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
